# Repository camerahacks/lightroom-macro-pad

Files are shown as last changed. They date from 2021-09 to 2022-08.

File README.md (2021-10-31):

More camera and photography related hacks @ [{DPHacks}](https://dphacks.com/) Blog

# Adobe Lightroom Macro Pad

This project started as a Raspberry Pi Pico Lightroom Macro Pad based on CircuitPython but it is growing to include other controllers. It's designed to work with 7 or 10 mechanical switches. One switch for choosing the mode and the other switches to execute the macros/shortcuts. You can modify the code and create your own shortcuts/macros.

Lightroom Macro Pad - Raspberry Pi Pico Pi Pico Macro Pad for Lightroom Classic

Although the firmware for this project is functional, this is a work in progress. If you find any bugs or issues, please let me know.

It can be easily ported to other microcontrollers by modifying a few variables in ```config.py```. For example, I've since created a macro pad to be used with Pimoroni's Tiny 2040 board.

I periodically add more pictures and details so it is easier for other folks to create their own macro pad.

## Lightroom Classic Shortcut Reference

<a href="https://helpx.adobe.com/lightroom-classic/help/keyboard-shortcuts.html" target="_blank">https://helpx.adobe.com/lightroom-classic/help/keyboard-shortcuts.html</a>

## Libraries/Dependencies
Make sure you have these in the lib folder on your board:
* <a href="https://github.com/adafruit/Adafruit_CircuitPython_HID" target="_blank">Adafruit_HID</a>

### Keycode Reference

<a href="https://github.com/adafruit/Adafruit_CircuitPython_HID/blob/master/adafruit_hid/keycode.py" target="_blank">https://github.com/adafruit/Adafruit_CircuitPython_HID/blob/master/adafruit_hid/keycode.py</a>

## Versions (READ THIS)

V0.7 Complete rework of the macro setup. It's much easier to edit and create macros. Macro configuration now lives in ```config.py```

V0.5 (in progress/main branch) transitions to Circuit Python's new Keypad API that allows key pin and matrix scans. This feature is only available in Circuit Python 7.0.0.

V0.1 works on CircuitPython 6.2.0 and above

## Coming Soon - Wishlist

* ~~Support 10-Switch layout~~ (done)
* Ability to scan a diode matrix (WIP)
* ~~Pimoroni Tiny 2020 Case~~ (done)

## Switch Layout

3D printable files are available for both layouts. 

7-switch: Switches 0-5 are used for macros and switch 6 is used for switching modes.

```
|     |   0   |   1   |   2   |
|  6  |   3   |   4   |   5   |
```

10-switch: Switches 0-8 are used for macros and switch 9 is used for switching modes.
```
|     |   0   |   1   |   2   |
|     |   3   |   4   |   5   |
|  9  |   6   |   7   |   8   |
```

## 3D Printing/ Case

Print the case in any material you choose. The bottom part on the 7-switch layout is just pressure fitted into the top piece using a 0.1mm tolerance. The bottom also has stand-offs for fitting the Pico.

The 10-switch case uses round magnets to snap the case parts together. Here is a link to the magnets I used: https://amzn.to/3CPtB5V (affiliate link), they are 5x2mm (diameter x thickness) magnets.

The case uses standard MX spacing, meaning you can use any MX compatible switches and keycaps.

STL and 3mf files can be found in the ```case``` folder.

## Keycaps

I'm using relegendable keycaps from X-keys (affiliate link: https://amzn.to/3gmbBYO) but you can use any keycap you'd like. I created a few icons so I can remember what each switch is mapped to. The legend SVG file can be found in the ```/keycaps``` folder.

## PCB

I created a simple PCB that makes the whole process a lot more plug and play. Creating these things actually takes a lot of time so I'm not releasing the PCB as open source just yet. If you are interested, you can head over to the <a href="https://www.etsy.com/shop/DPHacks" target="_blank">Etsy store</a> I setup to sell some electronic related items.

Just like the case, the PCB has MX spacing. I'll be releasing a 3D model of the PCB so you can design your own case if needed.

Lightroom Macro Pad - PCB

Lightroom Macro Pad - PCB

## Wiring the Macro Pad (Handwire version)

Lightroom Macro Pad - Raspberry Pi Pico Pi Pico Macro Pad for Lightroom Classic Wiring

Connect one of the pins on the switches to one of the ground (GND) pins on the Raspberry Pi Pico. The switches don't have a polarity, so you can choose which pin is connected to GND. There is no right or wrong. You can see in the picture above that all of the GND pins on the switches are connected with the white wire. The white wire is then connected to a GND pin on the Pico.

Connect the other free pin on the switches to a corresponding GPIO pin on the Pico. Take note of which switch is connected to which GPIO pin so you can edit the firmware code accordingly. Again, there is no right or wrong here, you can pick any of them.

## How to edit ```config.py```

### Starting with v0.7

Starting with version 0.7 the board pin and macro configuration are done in ```config.py```. You shouldn't have to make any changes to ```code.py```

Make changes to the code block below if you will be using different pins on your board.

```python
# Pi Pico     SW0        SW1        SW2        SW3        SW4        SW5        SW6         SW7         SW8         SW9       #
board_pins = (board.GP0, board.GP1, board.GP2, board.GP6, board.GP8, board.GP7, board.GP11, board.GP13, board.GP12, board.GP16)
```

Next, edit the code block below. (I'm working on creating a web based tool that will create ```config.py``` for you)

The example below has two modes: Culling and Library. Each mode has 9 macros configured since the keypad has 9 switches.

```python
configvar = [{"name":"Culling", # Mode Name
            "color":"red", # Mode Color, only used on devices with RGB led
            "macros":
                    [
                    {"Name":"grid", "keycomb":[Keycode.G]}, # Each macro has a name and a key combination. Keycode reference linked above
                    {"Name":"oneToOneZoom", "keycomb":[Mouse.LEFT_BUTTON]},
                    {"Name":"crop", "keycomb":[Keycode.R]},
                    {"Name":"loupe", "keycomb":[Keycode.E]},
                    {"Name":"increaseFlag", "keycomb":[Keycode.CONTROL, Keycode.UP_ARROW]},
                    {"Name":"toggleFilters", "keycomb":[Keycode.CONTROL, Keycode.L]},
                    {"Name":"goPrevious", "keycomb":[Keycode.LEFT_ARROW]},
                    {"Name":"decreaseFlag", "keycomb":[Keycode.CONTROL, Keycode.DOWN_ARROW]},
                    {"Name":"goNext", "keycomb":[Keycode.RIGHT_ARROW]}
                    ]
            },
            {"name":"Library", # Second mode starts here
            "color":"blue",
            "macros":
                    [
                    {"Name":"grid", "keycomb":[Keycode.G]},
                    {"Name":"oneToOneZoom", "keycomb":[Mouse.LEFT_BUTTON]},
                    {"Name":"crop", "keycomb":[Keycode.R]},
                    {"Name":"loupe", "keycomb":[Keycode.E]},
                    {"Name":"increaseFlag", "keycomb":[Keycode.CONTROL, Keycode.UP_ARROW]},
                    {"Name":"toggleFilters", "keycomb":[Keycode.CONTROL, Keycode.L]},
                    {"Name":"goPrevious", "keycomb":[Keycode.LEFT_ARROW]},
                    {"Name":"decreaseFlag", "keycomb":[Keycode.CONTROL, Keycode.DOWN_ARROW]},
                    {"Name":"goNext", "keycomb":[Keycode.RIGHT_ARROW]}
                    ]
            }]
```

## How to edit ```boot.py```

The options below only work on CircuitPython 7.0.0 or higher, if you have a lower version, these settings will just be ignored.

### Disabe CIRCUITPY drive

Disable the Raspberry Pi Pico mass storage device. This will prevent the Raspberry Pi Pico from showing as an additional drive on your computer.
```python
_DISABLEUSB = 1
```

The most graceful way to enable the CIRCUITPY mass storage device again is to enter REPL and run the code below. The extra line returns match the carriage returns needed to run this code block in REPL with the correct python indentation.

```python
import storage
storage.remount("/", readonly=False)
with open('boot.py') as f:
    newText=f.read().replace('_DISABLEUSB = 1', '_DISABLEUSB = 0')

with open('boot.py', 'w') as f:
    f.write(newText)

```
Another option is to nuke the ```boot.py``` file altogether. Enter REPL and run the code below. Easier to run and to remember but definitely not as graceful.

```python
import os
os.remove('boot.py')
```
A soft reset through REPL does not execute the ```boot.py``` file, you have to either bridge the RUN and GND pins OR disconnect and reconnect the USB cable to make your board run the boot code.

### Disable REPL

Disable the console USB device, which means you won't be able to connect a serial monitor and enter REPL. If you disable REPL and USB Device (option above), you can lock yourself out of the board. So, make sure you know what you are doing before enabling both options

```boot.py``` has a built-in failsafe option to push the Mode switch during boot so you can regain console/REPL access. Make sure to test the Mode key on your macro pad before enabling this option.
```python
_DISABLEREPL = 1
```

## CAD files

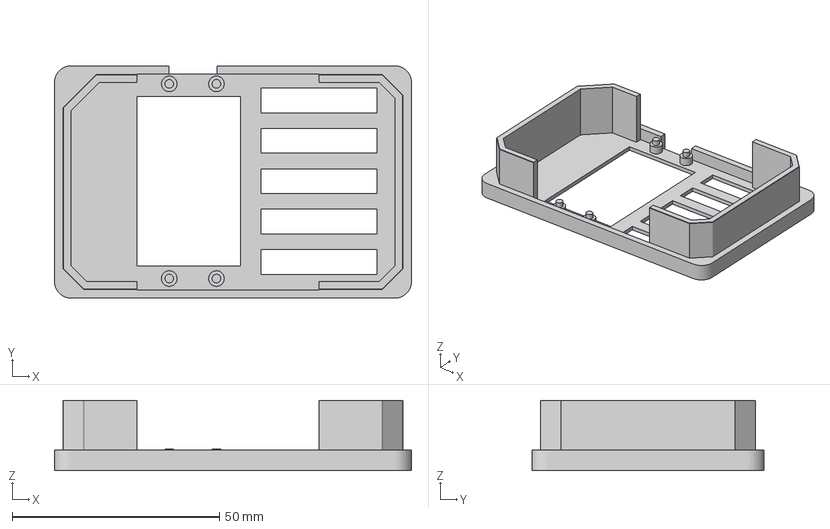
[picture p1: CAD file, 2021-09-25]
case/7_SW_Case_Bottom.3mf
86.2 x 56.1 x 17.0 mm

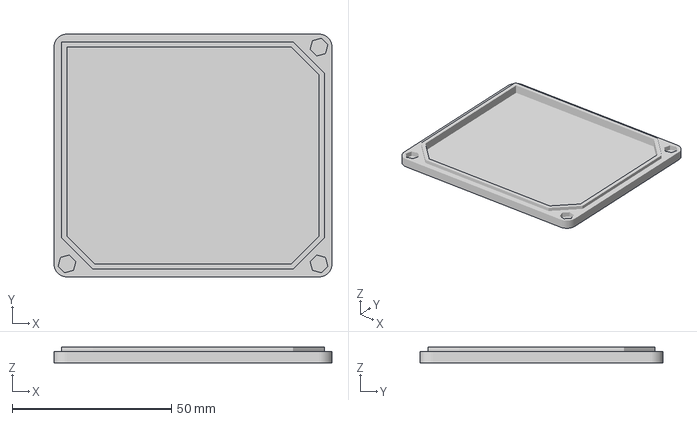
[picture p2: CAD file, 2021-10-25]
case/Tiny 2040/10_SW_Case_Tiny_2040_Bottom.3mf
87.2 x 76.2 x 5.00 mm

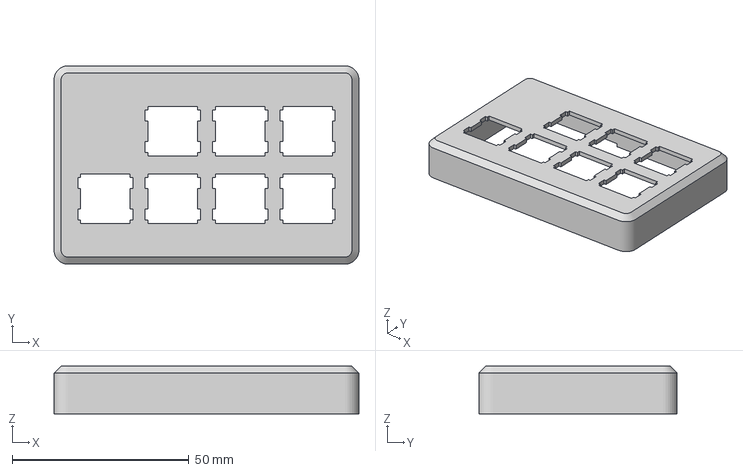
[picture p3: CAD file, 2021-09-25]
case/7_SW_Case_Top.3mf
86.2 x 56.1 x 13.5 mm

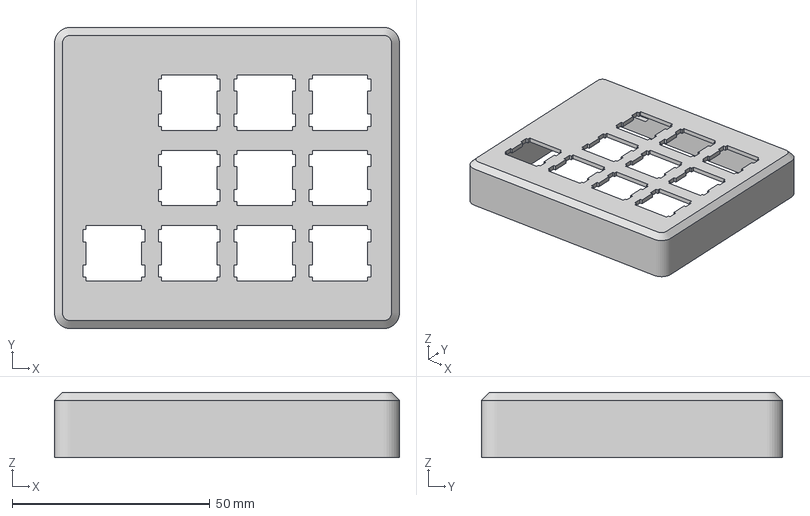
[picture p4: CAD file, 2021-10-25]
case/Tiny 2040/10_SW_Case_Tiny_2040_Top.3mf
87.2 x 76.2 x 16.5 mm

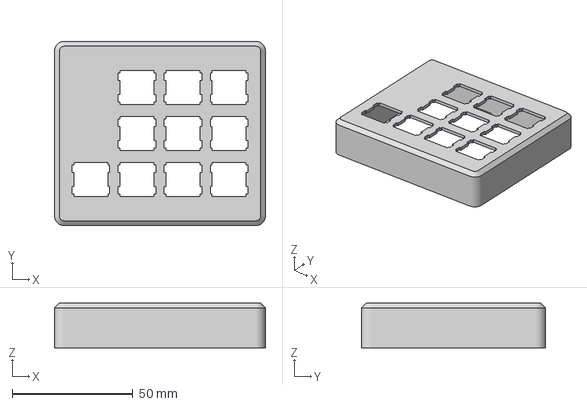
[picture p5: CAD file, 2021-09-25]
case/10_SW_Case_Top.3mf
87.2 x 76.2 x 18.5 mm

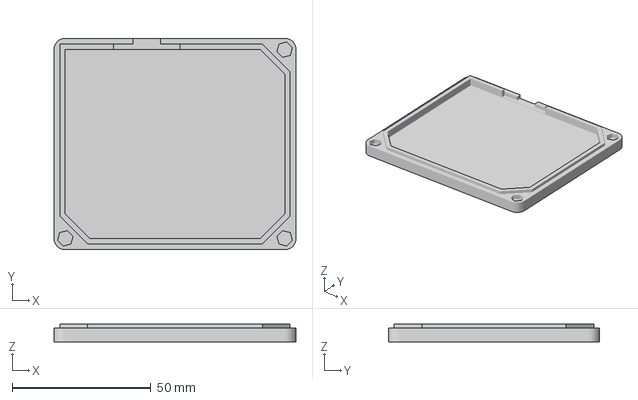
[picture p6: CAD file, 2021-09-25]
case/10_SW_Case_Bottom.3mf
87.2 x 76.2 x 6.40 mm

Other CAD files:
case/10_SW_Case_Bottom.stl
case/10_SW_Case_Top.stl
case/7_SW_Case_Bottom.stl
case/7_SW_Case_Top.stl
case/Tiny 2040/10_SW_Case_Tiny_2040_Bottom.stl
case/Tiny 2040/10_SW_Case_Tiny_2040_Top.stl

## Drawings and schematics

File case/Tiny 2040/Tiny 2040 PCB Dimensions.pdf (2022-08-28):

1.6 59.89 | R3 | R3 135° | 12.618.71 ¹².32

35.55

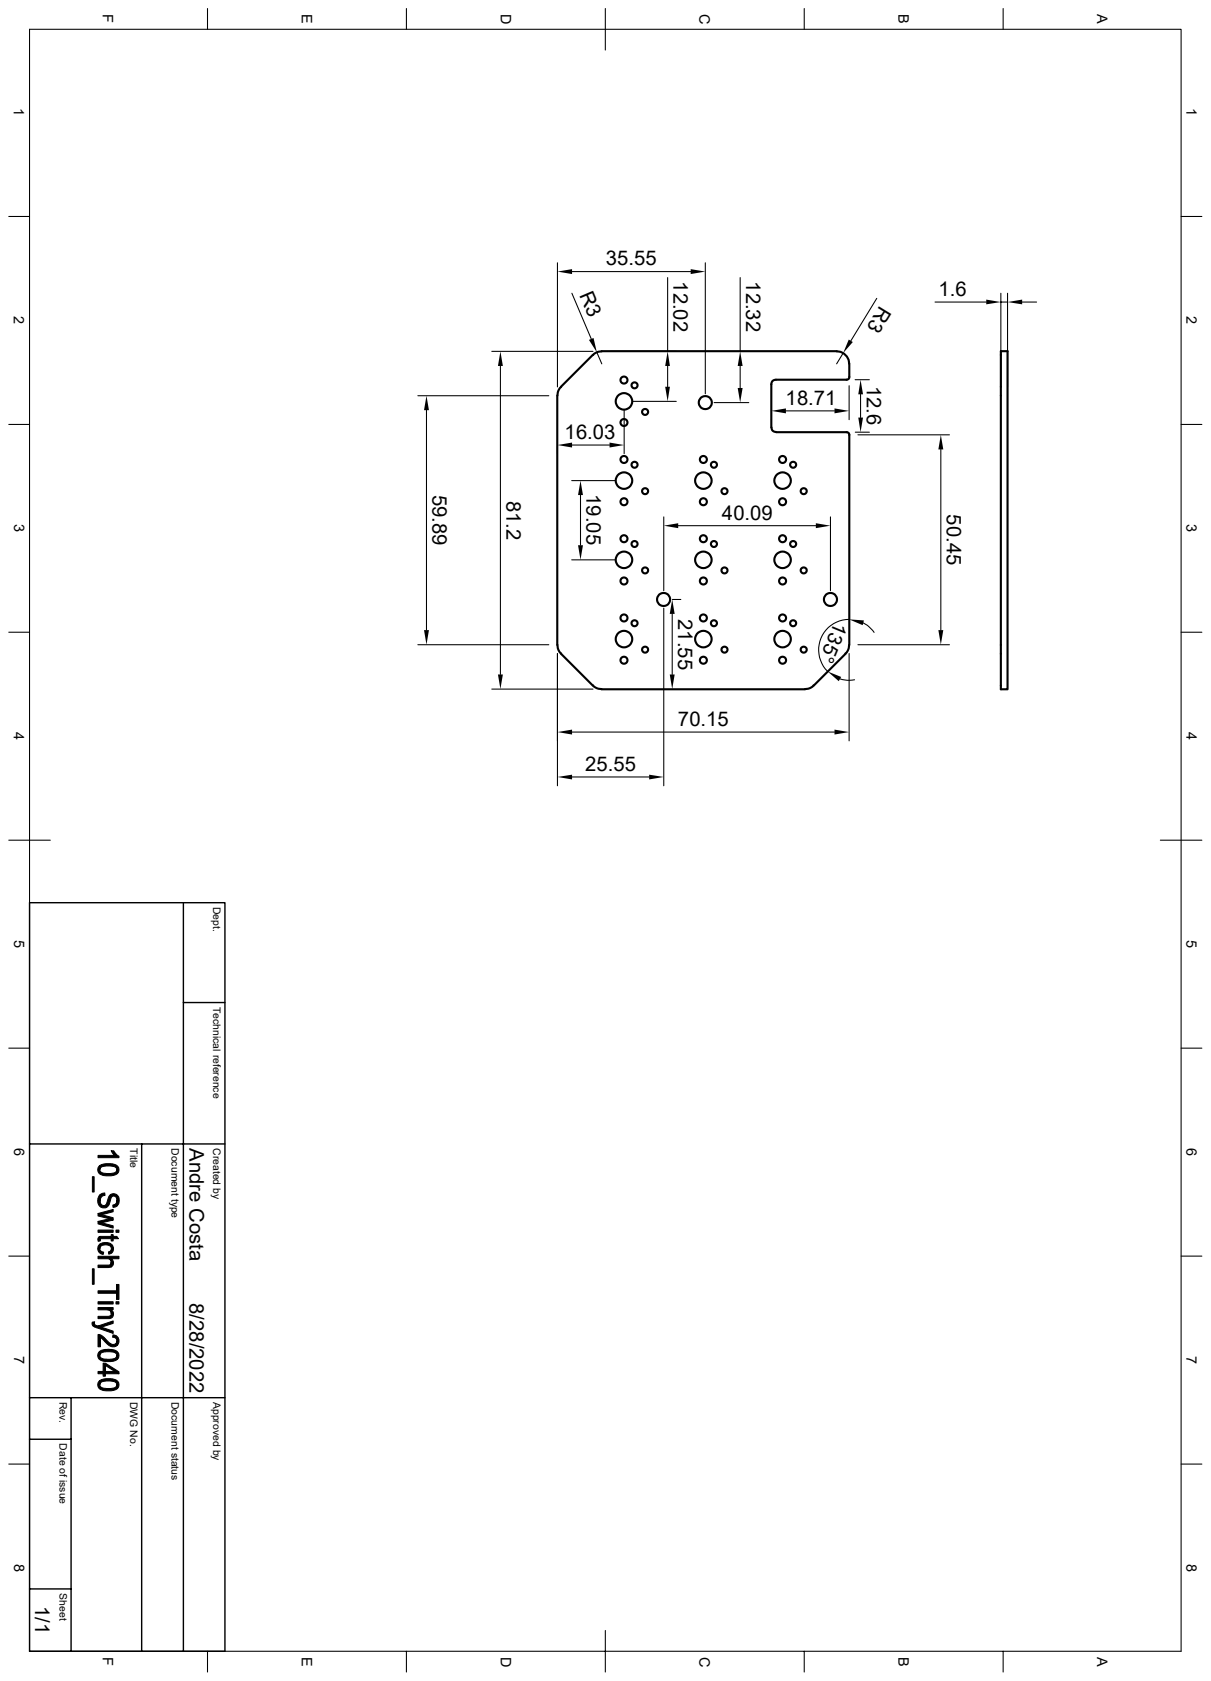
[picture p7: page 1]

1 A 2 3 4 5 6 7 8 1 2 3 4 5 6 7 8 FEDCB FEDCBA Dept. Technical reference Created by Approved by Title DWG No. Document type Document status Rev. Date of issue Sheet 8/28/2022 1/1 Andre Costa

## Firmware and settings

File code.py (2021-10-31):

# ------------------------------------------------------------ #
# Raspberry Pi Pico Lithroom Macro Pad
# @author André Costa dphacks.com
# @website dphacks.com

#
# Refer to the License file for permissions to use and distribute
# this software
# Refer to the README file how to edit the macros in this code
# This version of the code only runs on CircuitPython 7.0.0 and above
# ------------------------------------------------------------ #

# ------------------------
# Standard Libraries
# ------------------------

import time
import keypad
import board
import usb_hid

# ------------------------
# Additional Libraries
# These will have to be installed separately
# ------------------------

from adafruit_hid.keyboard import Keyboard
from adafruit_hid.mouse import Mouse
from adafruit_hid.keycode import Keycode
from adafruit_hid.keyboard_layout_us import KeyboardLayoutUS

# ------------------------
# Edit config.py to make changes to macros
# DO NOT edit the line in this file.
# ------------------------

import config

# ------------------------
# Definitions
# ------------------------

# LED - Pico's onboard lED is GP25
# led = digitalio.DigitalInOut(board.GP25)
# led.direction = digitalio.Direction.OUTPUT

# Keyboard device.
m = Mouse(usb_hid.devices)
kbd = Keyboard(usb_hid.devices)
layout = KeyboardLayoutUS(kbd)

# ------------------------
# Global Variables
# ------------------------

_VERSION = 'v0.7'
_DEBOUNCE = 0.020


# ------------------------
# Mode and Shortcut/Macro Classes
# ------------------------

class Macro:
    def __init__(self, name, keycomb):
        self.name = name
        self.keycomb = keycomb
    
    def macroName(self):
        return self.name

    def macroCall(self):
        kbd.send(*self.keycomb) #Expand keycode as parameters


class Mode:
    def __init__(self, name, color, macros):
        self.name = name
        self.color = color
        self.macros = macros

    def modeName(self):
        return self.name

    def modeColor(self):
        return self.color

    def modeMacros(self):
        mmacros = []
        for macros in self.macros:
            mmacros.append(Macro(macros['Name'], macros['keycomb']))
        
        return mmacros


modes = []
for mmodes in config.configvar:
    modes.append(Mode(mmodes['name'], mmodes['color'], mmodes['macros']))

curr_mode = modes[0]
mode_macros = curr_mode.modeMacros()
mode_color = curr_mode.modeColor()

# ------------------------
# Pin and Keypad configuration
# ------------------------

# 7-Switch Layout
# -------------------------------#
# |     |   0   |   1   |   2   |
# -------------------------------#
# | 6   |   3   |   4   |   5   |
# -------------------------------#

# 10-Switch Layout
# -------------------------------#
# |     |   0   |   1   |   2   |
# -------------------------------#
# |     |   3   |   4   |   5   |
# -------------------------------#
# | 9   |   6   |   7   |   8   |

# This part is commented for now. Only used if a diode matrix is in use

#km = keypad.KeyMatrix(
#    row_pins=(board.GP17, board.GP4, board.GP6),
#    col_pins=(board.GP10, board.GP8))

board_pins = config.board_pins

k = keypad.Keys(pins=board_pins, value_when_pressed=False, pull=True, interval=_DEBOUNCE)

# Mode switch/pin
#MODE_SW = keypad.Event(6, True) # 7-switch layout

MODE_SW = keypad.Event(9, True) # 10-switch layout

while True:
    # This part is commented for now. Only used if a diode matrix is in use
    #km_event = km.events.next()
    #if km_event:
        #print(len(km.events), "events queued")
        #print("matrix", km_event)

    k_event = k.events.get()

    if k_event == MODE_SW:
        # Change mode
        curr_mode = modes[(modes.index(curr_mode)+1) % len(modes)]
        # Load up the mode macros
        mode_macros = curr_mode.modeMacros()
        print(curr_mode.name) #DELETE
    
    elif k_event and k_event.pressed:
        #print("keys", k_event.key_number, k_event.pressed) #DELETE
        mode_macros[k_event.key_number].macroCall()
        print(mode_macros[k_event.key_number].macroName()) #DELETE

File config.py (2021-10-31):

# ------------------------------------------------------------ #
# Raspberry Pi Pico Lithroom Macro Pad
# @author André Costa dphacks.com
# @website dphacks.com

#
# Refer to the License file for permissions to use and distribute
# this software
# Refer to the README file how to edit the macros in this code
# This version of the code only runs on CircuitPython 7.0.0 and above
# ------------------------------------------------------------ #

from adafruit_hid.mouse import Mouse
from adafruit_hid.keycode import Keycode
import board

# ------------------------
# Pin and Keypad configuration
# ------------------------

# 7-Switch Layout
# -------------------------------#
# |     |   0   |   1   |   2   |
# -------------------------------#
# | 6   |   3   |   4   |   5   |
# -------------------------------#

# 10-Switch Layout
# -------------------------------#
# |     |   0   |   1   |   2   |
# -------------------------------#
# |     |   3   |   4   |   5   |
# -------------------------------#
# | 9   |   6   |   7   |   8   |


# Pi Pico     SW0        SW1        SW2        SW3        SW4        SW5        SW6         SW7         SW8         SW9       #
board_pins = (board.GP0, board.GP1, board.GP2, board.GP6, board.GP8, board.GP7, board.GP11, board.GP13, board.GP12, board.GP16)

# Add as many macros to the variable below as the number
# of buttons/switches in the same order you would like the
# buttons to be organized in. "macros" array index 0 will 
# be triggered by btn_0, index 1 by btn_1,...
# If a button shouldn't do anything, add the 'nothing' macro
# to its position

# Use the Keycode reference link below to edit the macros.
# There is no limit in how many key strokes to send at once but
# but keep in mind your computer might not be able to process all
# at once.
# https://github.com/adafruit/Adafruit_CircuitPython_HID/blob/master/adafruit_hid/keycode.py

# Refer to README.md on how to edit the code block below.

configvar = [{"name":"Culling",
            "color":"red",
            "macros":
                    [
                    {"Name":"grid", "keycomb":[Keycode.G]},
                    {"Name":"oneToOneZoom", "keycomb":[Mouse.LEFT_BUTTON]},
                    {"Name":"crop", "keycomb":[Keycode.R]},
                    {"Name":"loupe", "keycomb":[Keycode.E]},
                    {"Name":"increaseFlag", "keycomb":[Keycode.CONTROL, Keycode.UP_ARROW]},
                    {"Name":"toggleFilters", "keycomb":[Keycode.CONTROL, Keycode.L]},
                    {"Name":"goPrevious", "keycomb":[Keycode.LEFT_ARROW]},
                    {"Name":"decreaseFlag", "keycomb":[Keycode.CONTROL, Keycode.DOWN_ARROW]},
                    {"Name":"goNext", "keycomb":[Keycode.RIGHT_ARROW]}
                    ]
            },
            {"name":"Library",
            "color":"blue",
            "macros":
                    [
                    {"Name":"grid", "keycomb":[Keycode.G]},
                    {"Name":"oneToOneZoom", "keycomb":[Mouse.LEFT_BUTTON]},
                    {"Name":"crop", "keycomb":[Keycode.R]},
                    {"Name":"loupe", "keycomb":[Keycode.E]},
                    {"Name":"increaseFlag", "keycomb":[Keycode.CONTROL, Keycode.UP_ARROW]},
                    {"Name":"toggleFilters", "keycomb":[Keycode.CONTROL, Keycode.L]},
                    {"Name":"goPrevious", "keycomb":[Keycode.LEFT_ARROW]},
                    {"Name":"decreaseFlag", "keycomb":[Keycode.CONTROL, Keycode.DOWN_ARROW]},
                    {"Name":"goNext", "keycomb":[Keycode.RIGHT_ARROW]}
                    ]
            }]

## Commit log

2021-05-16 Code is functional, needs more shortcuts
    [code.py]
2021-06-13 Adding STL files
    [Macro Keeb Bottom.stl, Macro Keeb Top.stl]
2021-06-13 STL Readme
2021-06-26 Prepping for CircuitPython 7.0 and the new Keypad API
2021-07-16 Added 10-switch functionality
2021-08-01 More macros assigned to switches
2021-09-25 10-Switch Updates to README
2021-09-25 Added PCB Pictures
2021-09-25 Renamed STL files
    [7_SW_Case_Bottom.stl, 7_SW_Case_Top.stl]
2021-09-25 10 Switch case STL files
    [10_SW_Case_Bottom.stl, 10_SW_Case_Top.stl]
2021-09-25 Adding 3mf files
    [10_SW_Case_Bottom.3mf, 10_SW_Case_Top.3mf, 7_SW_Case_Bottom.3mf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]
2021-09-25 Updated with 10 switch information
2021-09-25 Added more details to case design exmplanation.
2021-10-25 Added Tiny 2040 Case
    [10_SW_Case_Tiny_2040_Bottom.3mf, 10_SW_Case_Tiny_2040_Bottom.stl, 10_SW_Case_Tiny_2040_Top.3mf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]
2021-10-31 Moving board specific code to their folders
2021-10-31 Split macro and board configuration into config.py
2022-08-28 PCB Dimensions
